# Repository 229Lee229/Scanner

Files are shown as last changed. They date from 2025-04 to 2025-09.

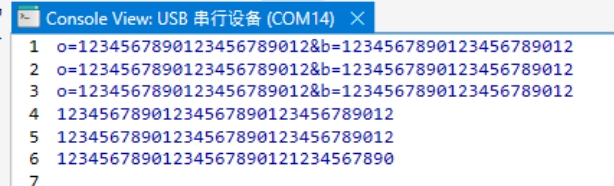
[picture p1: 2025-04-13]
Scanner_Manual/Picture_temp/com_data_stream.png

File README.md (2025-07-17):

# 扫码器通讯

----

### 扫码器使用手册V1

+   建立连接
    +   插入PC后, 上位机会通过发送指令 ==AT_ReadDeviceID\r== 来判断,如果扫码器验证成功, 则回应对应的ID, 例如: ==SN:SCANNER00009;MID:SCANNER01;FID:MESEEE01.== 这里FID是不变的

+   上电
    +   上电后, 单片机初始化操作,默认手动模式(即命令触发模式), 按下黄色键即可开启扫描状态(15s), 扫描过程中状态灯会闪烁, 扫描成功或者时间到状态灯熄灭.
+   连续模式
    +   当单片机收到上位机指令 ==AT_CONTINUOURS\r== 扫码器切换为连续扫码状态, 连续扫码状态黄色常量

+   按键
    +   V1版本按键有绿色和黄色, 在不管什么状态下, 按下按键, 触发上升沿中断, 向PC发送对应指令,
        +   NOTE: 在触发中断的过程中, 在没完成发送指令前, 不对串口2开启中断, 即按下按键,使能扫描器接收中断, 待按键松开,重新使能
    +   在单次模式下, 黄色按键不起作用, 改为按下扫描, 绿色全过程中正常使用.

---

+   版本

    +   ```text
        25/3/9
        	增加返回指令的识别,当主控向扫描器发送指令,若扫描器成功接收,则返回回应指令,此更改在接收中断函数(usart2)中进行判断.
        	在中断接收函数中判断指令02 00 00 01 00 33 31, 若正确,则在函数中清除缓存,以确保后续数据的准确接收.
        	在接收中断函数,只有三种情况,数据才会被程序处理.
        	1-回应指令,前文已说明过		
        	2-当最后一个字符为'.'			// DeviceID的回应
        	3-当最后一个字符为'\r'			// 扫码数据的回应
        	
        	以及在单次扫描模式中,即手动模式,在程序上是用命令触发模式,当按下按键,扫描器开始扫描,计时指定时间,这里是15s,15s中LED会闪烁提示,到时间后或扫码成功则熄灭.用到定时器3.考虑后续要不要加此功能.
        25/4/9
        	将黄灯在连续模式下改成常量,黄灯在手动模式下在扫描状态中闪烁不变
        	将发送二维码数据格式中的"CODE_DATA:"改成"A:"
        ```

+   摄像头常用命令

    +   读码时长
    +   ![](Scanner_Manual/Picture_temp/读码时长.png)

+   **1、USB转串口CH340驱动**

    +   这个设备是CH340驱动,如果不装此驱动,电脑会识别不出来这个USB设备

+   **2、读取设备ID**

    +   读取设备ID,判定目标设备,建立连接
        +   当USB Device连接到主机后，主机发送Device指令，读取设备ID: ==AT_ReadDeviceID== （以'\r'回车符CR结束,该ASCII码对应的十六进制是0x0D), Device收到后会回对应的设备ID,格式基本如：==SN:SCANNER00009;MID:SCANNER01;FID:MESEEE01.== 
        
        +   FID信息是固定不变的
        
            ```
            SN:产品序列号
            FID:厂商信息
            MID:产品型号
            ```

+   **3、扫码数据**

    +   当扫码器扫码成功后，会向主机发送码对应的数据，如（大致的每个码的数据像一下这样，这里的每行都是一个码的数据）：
    +   以前缀"A:"开头, 以回车符'\r'结束
    +   ![](Scanner_Manual/Picture_temp/com_data_stream.png)

+   **4、切换模式**

    +   扫码器上电默认手动扫描模式，由主机端控制是否切换为连续扫描模式

    +   **切换连续扫描模式(每条指令同样是以回车符CR作为结束)**
        +   指令: ==AT_CONTINUOUS== 
        
    +   **切换手动模式**
        
        +   指令: ==AT_MANUAL==
        
    +   发送完成, 设备成功接收到会回应主机:

        +   ```
            例如: AA 11 AB 10 0D
            AA: 帧头
            11: 状态回应类型
            AB: 表示OK            (FF表示错误)
            10: 异或校验和
            0D: 表示结束
            ```

+   **5、设备发送按键值**

                ● 当用户按下按键,设备会向PC发送指令.

                ● 当按键按下,发送五个字节: 

                ○ 

```
例如: AA 01 01 AA 0D
AA:为帧头
01:按键操作类型
第三个字节:按键值 (01 表示绿色按键按下,02表示黄色按键按下)
第四个字节:异或校验和
第五个字节:OD结束
```

                ● 同样以回车符CR结束

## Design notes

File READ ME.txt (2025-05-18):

此版本代码在原来基础上改进为双击触发单次模式, 
在单次模式下, 左键发送合格指令, 右键单击(上升沿触发)发送不合格指令,右键双击(下降沿触发)发送触发扫描指令
在400ms内有双次松开按键表示满足发送触发扫描条件, 同样的, 若800ms内有三次松开按键操作, 则第三次会被识别为指令指令.

增加在正常启动过程中, 若串口1收到指令 BOOT\r 则进入bootloader模式

定时器占用:
TIM1	当松开按键(上升沿触发中断)开启TIM1 计时1ms消抖		当TIM1时间到, pressCount++,同时TIM2开始计时400ms,
		若TIM2时间到, 判断pressCount=1 or =2, 在主循环中判断
TIM2	双击判断时间 400ms
TIM3	单次触发后闪烁提示 4Hz
TIM4	心跳	 2s

OBJ中的Scanner_V4.1.hex文件是第一个版本,测试基本可行,后续版本考虑去掉消抖定时器改为for延时 

20250512 Lee	mikasa229@gmail.com

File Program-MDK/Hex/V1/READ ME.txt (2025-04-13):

此程序用于调试扫描器到主机之间是否通讯正常 扫描成功驱动蜂鸣器
usart2用于STM32与扫描器之间的通讯		9600
usart1用于STM32与CH340G之间的通讯		115200
CH340G再将数据转成USB2.0数据发送给主机

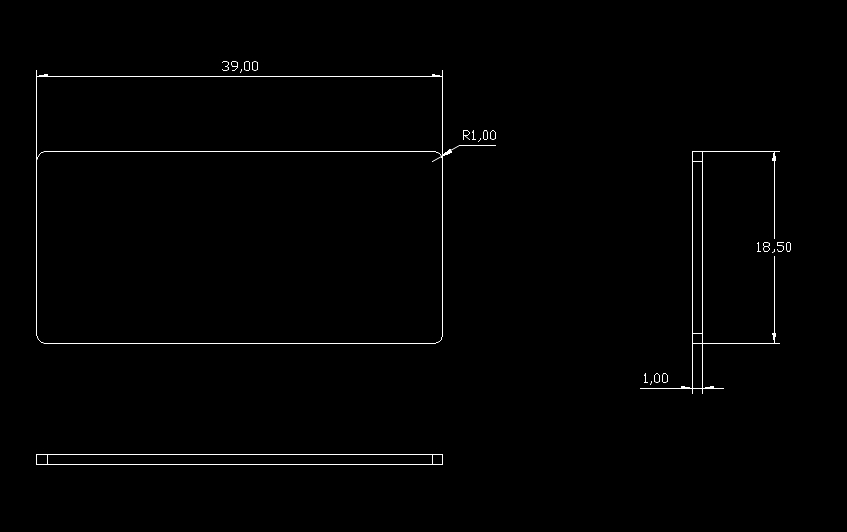
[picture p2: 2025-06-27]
Structure - Shell/亚克力板工程图.png

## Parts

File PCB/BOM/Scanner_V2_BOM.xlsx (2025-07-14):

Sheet: PCB
Comment | Designator | Footprint | Quantity |  | NOTE | LINK
ANT | ANT1 | IPX-2.0 | 1
Beep | BP1 | BEEP | 1 |  | Passive buzzer (scanner with built-in driver) | https://e.tb.cn/h.hRT3QYDlAHfo2lV?tk=ZTqZ41IBWqQ
106,0603 | C1, C4 | C0603 | 2
104,0603 | C2, C8, C9, C10, C11, C12, C13, C14, C17, C18, C19 | C0603 | 11
2.2uF,0603 | C3, C5 | C0603 | 2
12pF?,0603 | C6, C7 | C0603 | 2
22pF,0603 | C15, C16 | C0603 | 2
LED,0603 | D1, D4 | LED0603 | 2
LED | D2, D3 | LED-2.5mm | 2 |  | 3mm LED green (D2) and yellow (D3) | https://e.tb.cn/h.hRHjGvWTx35mATQ?tk=mqnt41sc0m7
1N4148 | D5 | 1N4148 | 1 |  | 1206 SOP-123
Comment | Designator5, Designator6 | TP_PWR | 2
Comment | Designator8, Designator9 | MARK-Point | 2
AFC01-S12FCA-00 | FPC1 | CONN-SMD-12P_AFC11-S12ICA-00 | 1 |  | 12p FPC connector, with a spacing of 0.5mm, vertical patch misalignment feet | https://e.tb.cn/h.hRHMwjfpqVUvsA0?tk=VT1y41sgr6b | FPC: https://e.tb.cn/h.hRUxhtFcibsN0M2?tk=kCpY41shlWU
Conn_1.25mm_4Pin_PLT | J1 | CONN-SMD_4P-P1.25_HCTL_HC-1.25-4PLT | 1 |  |  | https://e.tb.cn/h.hRUze6T23dEpF2G?tk=QSa241siz9R
TS665CJ | K1, K2 | KEY12*12 | 2 |  | 12*12*17 | https://e.tb.cn/h.hR5aV8lNxkFJfCl?tk=RHnc41s87Im
S8050 | Q1 | S8050 | 1
1K,0603 | R1, R2, R18 | R0603 | 3
0?,0603 | R3, R4, R7, R8, R9, R10, R12 | R0603 | 7
10K,0603 | R5, R6, R14, R15, R19 | R0603 | 5
4k7,0603 | R11 | R0603 | 1
1K?,0603 | R13 | R0603 | 1
100R,0603 | R16, R17 | R0603 | 2
K2-1107ST-A4DW-06 | SW1, SW2 | KEY-SMD_L6.2-W3.6-LS8.0 | 2
AMS1117-3.3 | U1 | AMS1117 | 1
CH9141K | U2 | CH9141K | 1 | NOTE: The peripheral circuit of the chip is not attached
32MHz | U3 | 32MHz_2016 | 1
STM32F103C8T6 | U4 | LQFP-48_L7.0-W7.0-P0.50-LS9.0-BL | 1 |  | OR APM32F103C8T6 LQFP-48 (Geehy)
CH340X | U5 | CH340X | 1
USB-5PIN | USB1 | MICRO-USB-SMD_MICROXNJ | 1 |  | 无边 micro 牛角 平口 5P母座 | https://e.tb.cn/h.hRhPDXoZbI5AlFG?tk=LGau41s9lSe
8MHz | Y1 | 8MHz | 1
Scanner module |  |  |  |  |  | https://e.tb.cn/h.hRHAoglssyOLvuv?tk=0PrV41sK2e4

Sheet: structure
结构物料
固定外壳螺丝 | 十字圆头自攻 PA2.8*12 | https://e.tb.cn/h.hRhCYvhqSnPUkvb?tk=ip3y41sx81W | 4 PCS
固定扫码器模组螺丝 | KM1.5*3 黑 | https://e.tb.cn/h.hR62wU4ZOz2AFte?tk=07V641syZBw | 4 PCS

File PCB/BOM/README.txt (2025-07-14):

V2版本支持Geehy芯片, 与V1版本不同的是在BOOT0引脚上拉低, 避免开机进入bootloader

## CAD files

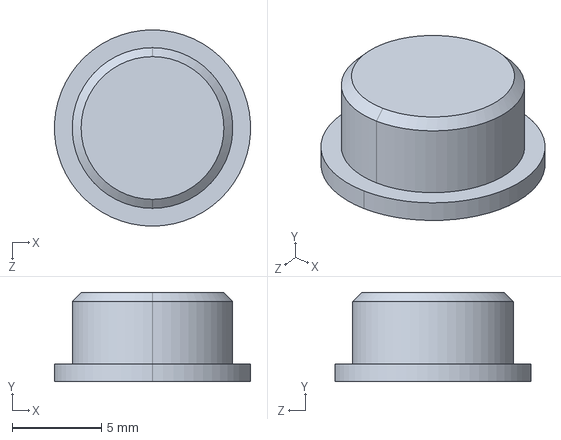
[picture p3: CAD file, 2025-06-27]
Structure - Shell/键帽.STEP
11.0 x 5.00 x 11.0 mm

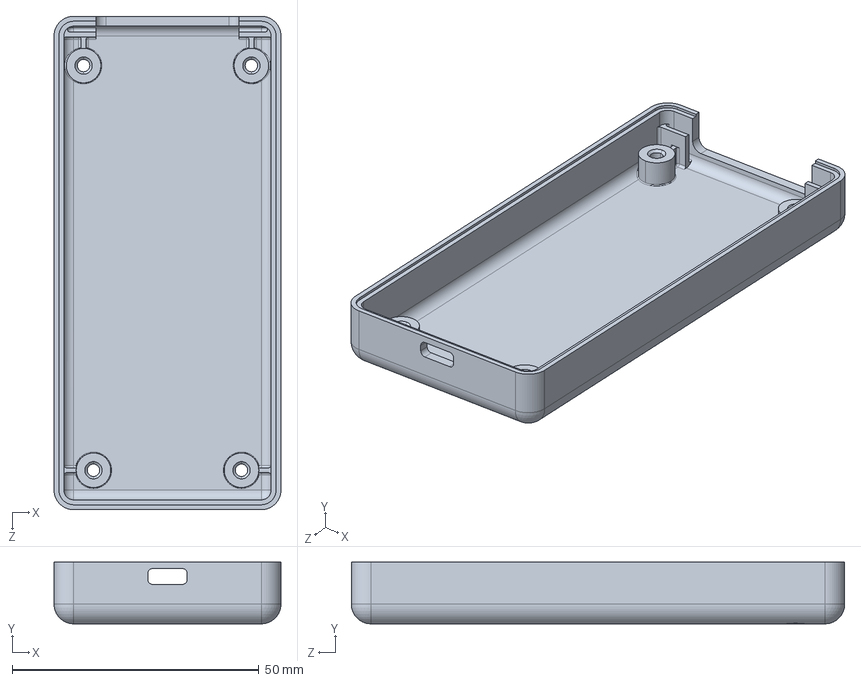
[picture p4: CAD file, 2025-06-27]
Structure - Shell/下壳.STEP
46.0 x 12.5 x 100.0 mm

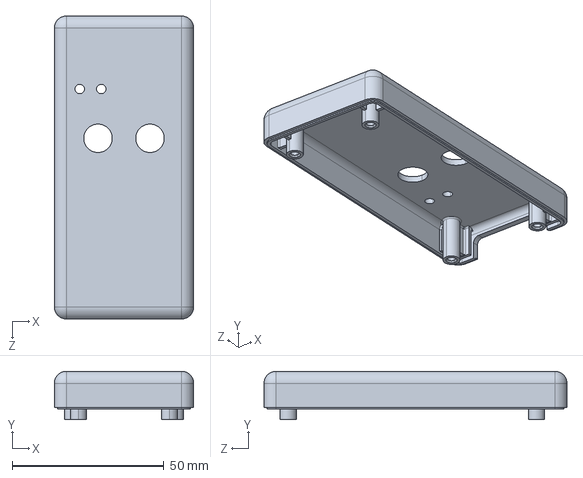
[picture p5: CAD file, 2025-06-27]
Structure - Shell/上壳.STEP
46.0 x 16.0 x 100.0 mm

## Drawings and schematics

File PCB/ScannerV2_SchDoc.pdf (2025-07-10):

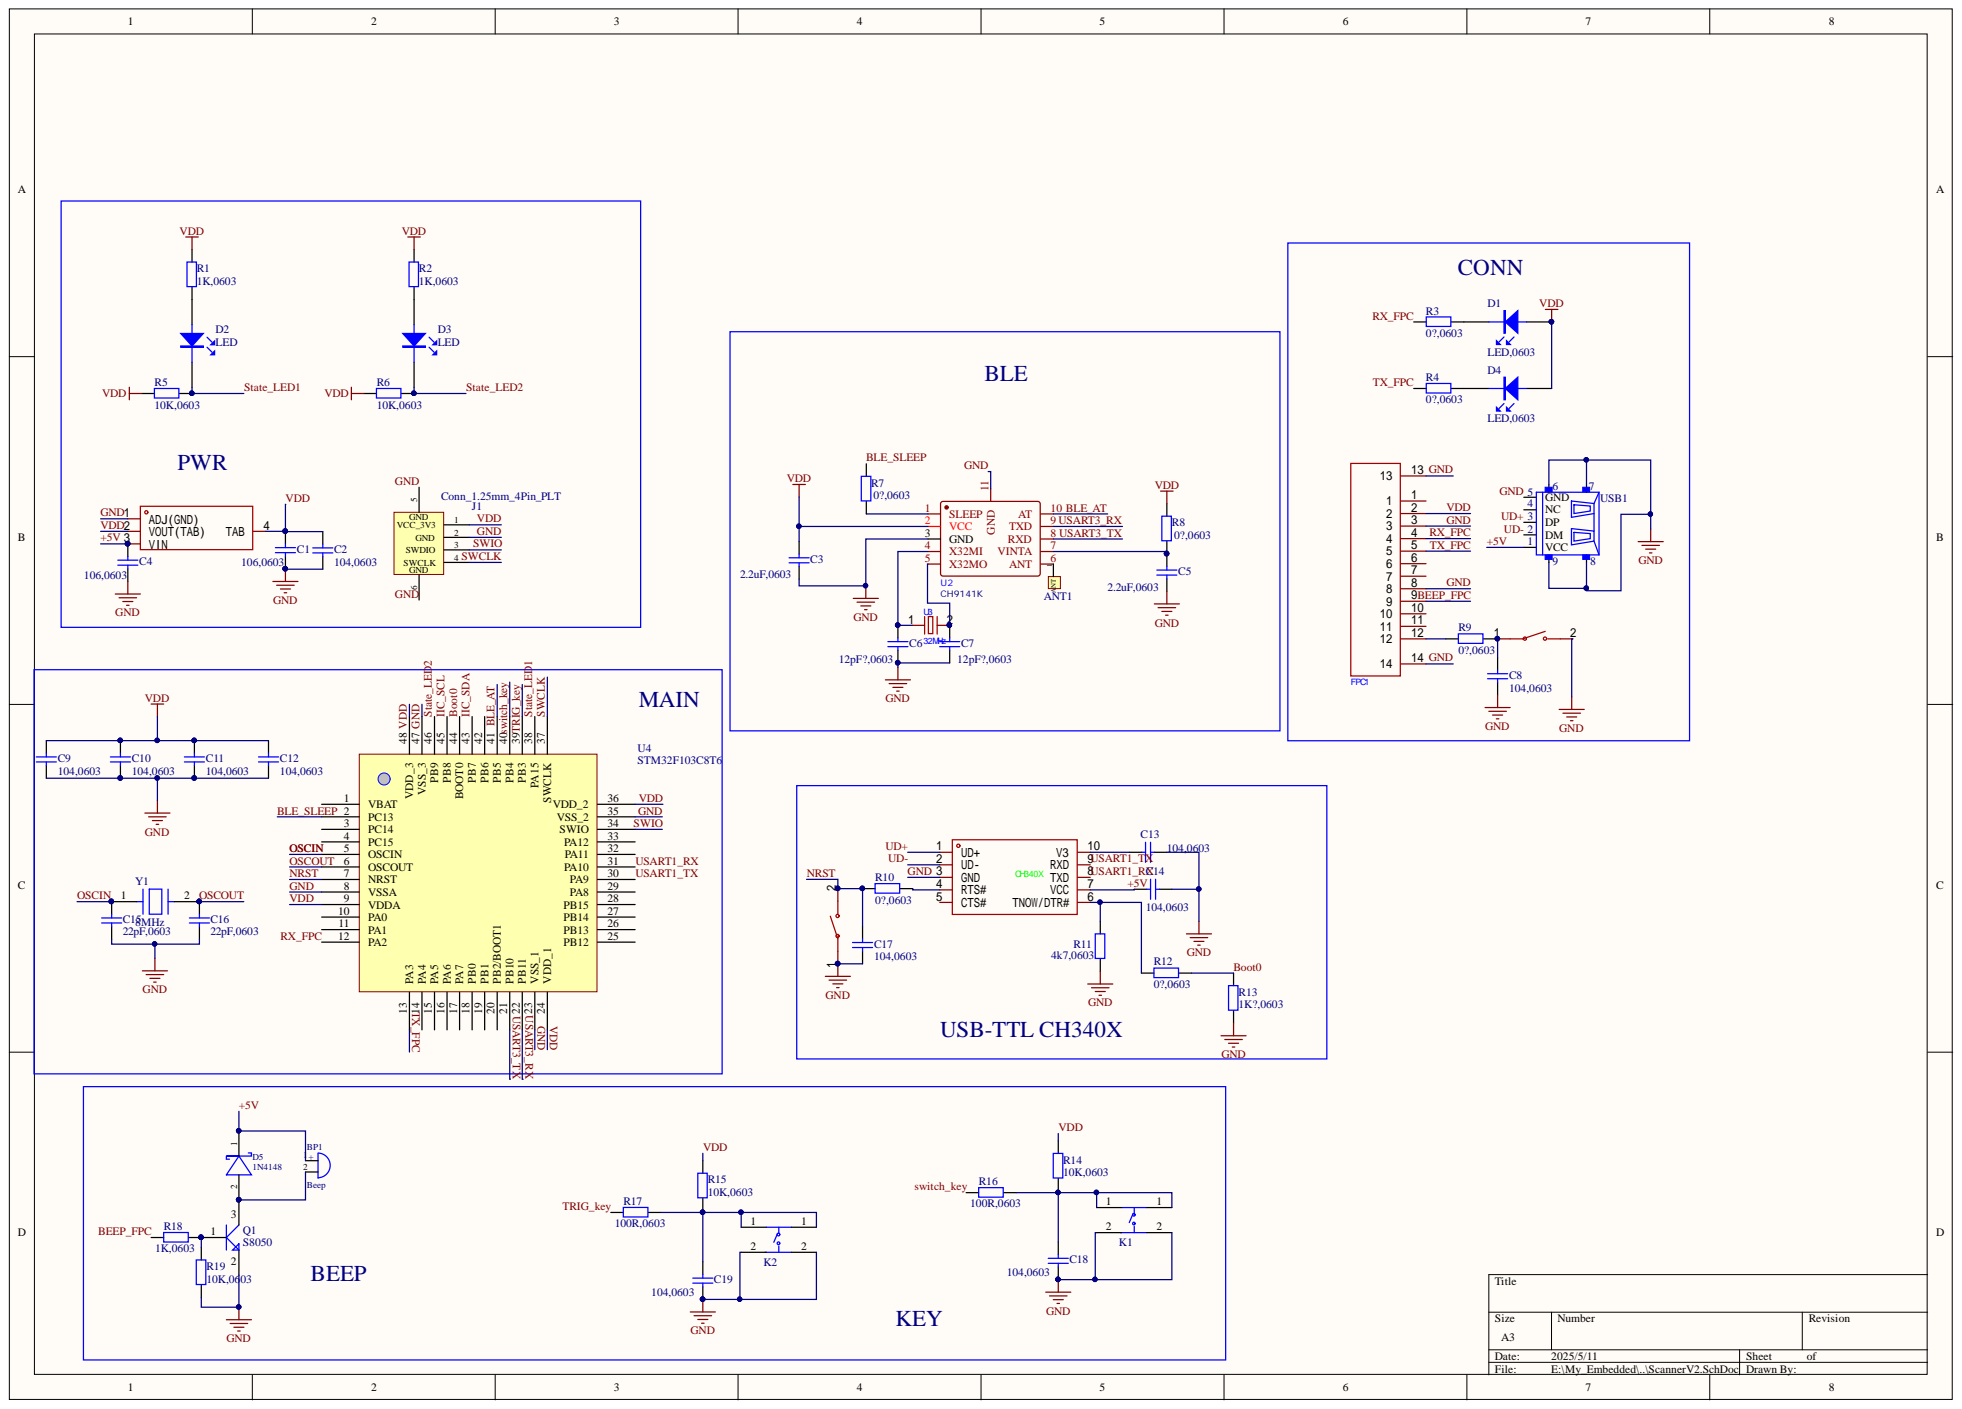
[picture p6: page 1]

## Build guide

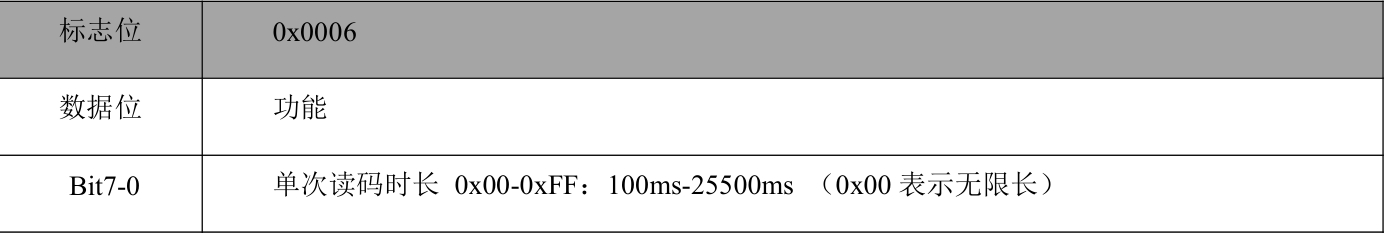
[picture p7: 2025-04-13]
Scanner_Manual/Picture_temp/读码时长.png

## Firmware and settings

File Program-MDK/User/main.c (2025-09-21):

/**********************************************************************
 * flie:  main
 * brief:  
 * Input:  
 * Output: 
 * Retval: 
 *
 * History--------------------------------------------------------------
 * Version       Date         Name    			Changes and comments
 *===7==================================================================
	V1.0		 4/9/2025    Lee				增加在连续模式下,yellow led常量;在手动下,yellow60闪烁不变	
	V1.1		 4/9/2025	 Lee				更改扫码数据发送格式,'DATA_CODE:'改成'A:'
	V1.2		 5/3/2025 	 Lee				在单次触发模式下,按下触发键(右键),扫码器开始扫描并且发送质检不合格指令
	V2.0		 5/4/2025	 Lee				增加串口接收Boot指令,进行重启通过串口烧程序
 ***********************************************************************/


#include "stm32f10x.h"                  // Device header
#include "My_include.h"

// 接收缓存
extern char Rx_scanner_temp[rx_buffer_scanner_MAX]; 
extern uchar rx_buffer_scanner[rx_buffer_scanner_MAX];  
extern char Rx_ch340_temp[rx_buffer_scanner_MAX];
extern uchar rx_buffer_ch340[rx_buffer_scanner_MAX];

// 接收字符串索引
extern uint16_t scanner_rx_index;
extern uint16_t ch340_rx_index;

// 接收标志位
extern bool data_REC_scanner_Flag;
extern bool data_REC_ch340_Flag;

// 手动标志位(默认开启)
bool MANUAL_FLAG = true;

bool key1 = false;

// 扫码数据标志位
bool Scan_Data_Flag = false;


extern volatile uint8_t click_event;		// 单机事件标志
extern volatile uint8_t double_click_event;// 双击事件标志
extern volatile int blink_cnt;


volatile bool  sleep_flag = false;
// ??ARM EABI???????
void __aeabi_assert(const char *expr, const char *file, int line) {
  // ????????????(????????)
  char msg[128];
  sprintf(msg, "Assert failed: %s, file %s, line %d\r\n", expr, file, line);
  printf("%s",(uint8_t*)msg);
  
  // ???????,????????
  while(1);
}
int main(void){
	/* 4/4 新增 */
//	RCC_DeInit();		// 复位时钟配置
//	// 开启HSE并等待就绪
//	RCC_HSEConfig(RCC_HSE_OFF);
//	while(RCC_GetFlagStatus(RCC_FLAG_HSIRDY) == RESET);
//	
//	// 配置PLL: HSE不分频, 倍频9倍
//	RCC_PLLConfig(RCC_PLLSource_HSI_Div2,RCC_PLLMul_9);
//	
//	// 开启PLL并等待就绪
//	RCC_PLLCmd(ENABLE);'
//	while (RCC_GetFlagStatus(RCC_FLAG_PLLRDY) == RESET);
//	// 切换系统时钟源为PLL
////	RCC_SYSCLKConfig(RCC_SYSCLKSource_PLLCLK);
//	while (RCC_GetSYSCLKSource() != 0x00); // 确认切换成功

//	// 更新系统时钟全局变量
//	SystemCoreClockUpdate(); // 此变量在代码中用于跟踪主频	
	
	SystemInit();
	RCC_APB2PeriphClockCmd(RCC_APB2Periph_AFIO,ENABLE);
    GPIO_PinRemapConfig(GPIO_Remap_SWJ_JTAGDisable,ENABLE);			// 取消PB3 PB4 PA15的JTAG模式 改为普通IO
	TIM1_Init();

	SCANNER_UART2_Init(115200);
	CH340_UART1_Init(115200);
	// Send_Manual_Cmd();
	// Send_Continuous_Cmd();
	// 按键初始化
	key_Init();
	LED_State_Init();
	STATUS_LED_GREEN_ON();			// 状态灯 低电平点亮
	
	// 加调试
	assert(PAout(15) == 1);
	
	// Send_Single_Cmd(15);
	// Send_ReadDeviceID_Cmd();
	Send_Cmd_trig_Cmd();
	
	Delay_ms(100);
	// 清除缓冲区
	memset(rx_buffer_scanner, 0, sizeof(rx_buffer_scanner));	
	memset(Rx_scanner_temp, 0, sizeof(Rx_scanner_temp));	
	scanner_rx_index = 0;
	data_REC_scanner_Flag = false;
	
#ifdef DEBUG_PRINT	
	printf("Initialization Successful!\r\n");
#endif	
	HeartBeat_TIM_Init();
	
	
	TIM_Double_Click_Init();
	// Write_App_Version();
//	if(Erase_Flag_Sector() == FLASH_COMPLETE) {
//    printf("Erase suc!\r\n");
//    // ????????FF
//    uint32_t* p = (uint32_t*)APP_VERSION_ADDRESS;
//    if(*p == 0xFFFFFFFF) {
//        printf("Erase fail\r\n");
//    }
//} else {
//    printf("????,???:%d\r\n", FLASH_GetStatus());
//}
	// Erase_Flag_Sector();
				// printf("1");

	while(1){

		
		if(data_REC_scanner_Flag == true){
			Handle_RX_Scanner();
		}
		if(data_REC_ch340_Flag == true){
			Handle_RX_CH340();
		}
		
		
		
		if(click_event){
			click_event = 0;
			uint8_t frame[5];
			frame[0] = 0xAA;
			frame[1] = 0x01;
			frame[2] = 0x02;
			frame[3] = calculate_xor_checksum(frame,3);		// 异或校验
			frame[4] = 0x0D;	
			for(uint8_t i= 0;i < 5;i++){
			USART_SendData(CH340_UART1,frame[i]);
				while(USART_GetFlagStatus(CH340_UART1, USART_FLAG_TXE) == RESET){
		#ifdef DEBUG_PRINT_2 			
					// printf("Send_Cmd_trig_Cmd_flag_wait...\r\n");
		#endif
				} // 等待发送完成;
			
			}
		}
		if(double_click_event){
			double_click_event = 0;
				if(MANUAL_FLAG == true){				// 上电默认手动标志位(即命令触发标志位)为真
					TIM_ITConfig(TIM3, TIM_IT_Update, ENABLE); 
		#ifdef 	DEBUG_PRINT
					key1 = true;
		#endif
					blink_cnt = 0;
					Send_Cmd_trig_Cmd();
					for(int i  = 0; i <= 555;i++){
						;
					}
					Send_Cmd_trig_ON_Cmd();			
						
				} // else{
			
		}
		
		
		
//		if(key1 == true && data_REC_scanner_Flag == false){
//			memset(rx_buffer_scanner, 0, sizeof(rx_buffer_scanner));	
//			memset(Rx_scanner_temp, 0, sizeof(Rx_scanner_temp));	
//			scanner_rx_index = 0;	
//		}
//		if(	scanner_rx_index != 0){
//			printf("%s",rx_buffer_scanner);
//				memset(rx_buffer_scanner, 0, sizeof(rx_buffer_scanner));	
//	memset(Rx_scanner_temp, 0, sizeof(Rx_scanner_temp));	
//	scanner_rx_index = 0;
//		}
		// printf("%s",rx_buffer_ch340);
	}
	
	
}

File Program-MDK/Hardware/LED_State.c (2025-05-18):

#include "My_include.h"


volatile int blink_cnt = 0;
void LED_State_Init(void){
	
	RCC_APB2PeriphClockCmd(RCC_APB2Periph_GPIOB | RCC_APB2Periph_GPIOA,ENABLE);
	GPIO_InitTypeDef  GPIO_InitStructure;
	// 初始化PA15 
	GPIO_InitStructure.GPIO_Mode = GPIO_Mode_Out_PP;
	GPIO_InitStructure.GPIO_Pin = GPIO_Pin_15;
	GPIO_InitStructure.GPIO_Speed = GPIO_Speed_50MHz;
	GPIO_Init(GPIOA,&GPIO_InitStructure);

	// 初始化PB9
	GPIO_InitStructure.GPIO_Mode = GPIO_Mode_Out_PP;
	GPIO_InitStructure.GPIO_Pin = GPIO_Pin_9;
	GPIO_InitStructure.GPIO_Speed = GPIO_Speed_50MHz;
	GPIO_Init(GPIOB,&GPIO_InitStructure);
	// 先拉低 后面再闪烁
	GPIO_WriteBit(GPIOB,GPIO_Pin_9,Bit_SET);
	GPIO_WriteBit(GPIOA,GPIO_Pin_15,Bit_SET);
	
	
	// 初始化定时器3 来在单次模式中扫码 LED闪烁 扫码成功或扫码时间到停止LED
	RCC_APB2PeriphClockCmd(RCC_APB2Periph_AFIO, ENABLE);
    RCC_APB1PeriphClockCmd(RCC_APB1Periph_TIM3, ENABLE);
	TIM_TimeBaseInitTypeDef TIM_TimeBaseStructure;
    
    TIM_TimeBaseStructure.TIM_Period = 1800;         // ARR	
    TIM_TimeBaseStructure.TIM_Prescaler = 9200;        // PSC	
    TIM_TimeBaseStructure.TIM_ClockDivision = TIM_CKD_DIV1;
    TIM_TimeBaseStructure.TIM_CounterMode = TIM_CounterMode_Up;
    TIM_TimeBaseInit(TIM3, &TIM_TimeBaseStructure);
    
    TIM_ITConfig(TIM3, TIM_IT_Update, DISABLE);         // 
    TIM_Cmd(TIM3, ENABLE);                             // 	
	
	// 配置NVIC
	NVIC_InitTypeDef NVIC_InitStructure;
	NVIC_PriorityGroupConfig(NVIC_PriorityGroup_2);
    NVIC_InitStructure.NVIC_IRQChannel = TIM3_IRQn;
    NVIC_InitStructure.NVIC_IRQChannelPreemptionPriority = 1;
    NVIC_InitStructure.NVIC_IRQChannelSubPriority = 1;
    NVIC_InitStructure.NVIC_IRQChannelCmd = ENABLE;
    NVIC_Init(&NVIC_InitStructure);
	
}
void TIM3_IRQHandler(void) {
    if (TIM_GetITStatus(TIM3, TIM_IT_Update) == SET) {
		
		blink_cnt++;
		PBout(9) = !PBout(9);
		if(blink_cnt == 70){
			PBout(9) = 1;
			TIM_ITConfig(TIM3, TIM_IT_Update, DISABLE); 
			blink_cnt = 0;
			
		}
        TIM_ClearITPendingBit(TIM3, TIM_IT_Update); // 清除中断标志位
    }
}

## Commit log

2025-06-27 add shell file
    [上壳.STEP, 下壳.STEP, 键帽.STEP]
2025-07-10 add PCB
    [ScannerV2.PcbDoc, ScannerV2.SchDoc]
2025-07-11 stop track unless
2025-07-14 add BOM
    [Scanner_V2_BOM.xlsx]
2025-07-15 apply ignore
    [ScannerV2.PcbDoc, ScannerV2.SchDoc, Scanner_V2_BOM.xlsx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]
